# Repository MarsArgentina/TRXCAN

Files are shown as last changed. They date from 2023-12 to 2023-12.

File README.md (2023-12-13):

# TRXCAN
This project aims to develop an open platform that allows CANSAT developers to easily add RF communications and APRS tracking. It will also add GPIO and flight computer control a weather balloon.

This project is intended to fit inside an standardized CANSAT, measuring 66mm in diameter and 3CM in height. 

This project is currently in development. 

Currently the intended platform can be viewed in the following images:

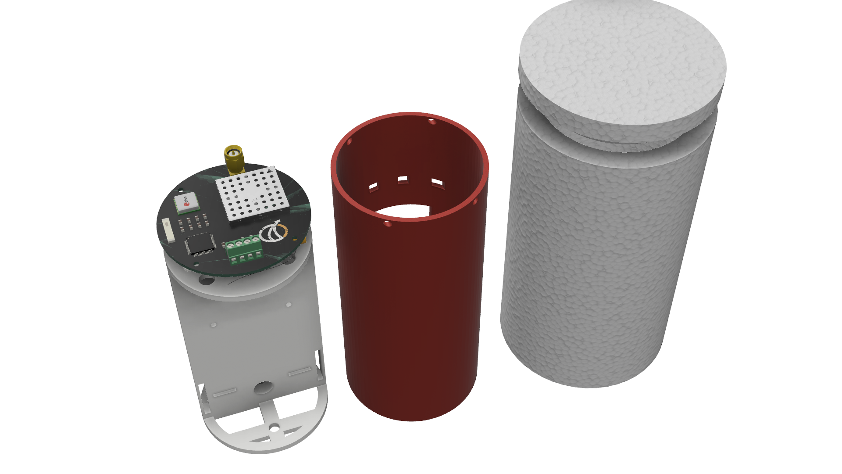
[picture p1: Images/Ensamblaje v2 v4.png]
Exploded view of assembly


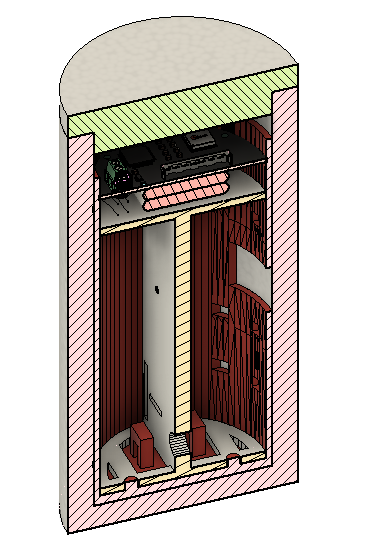
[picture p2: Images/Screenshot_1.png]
Section view of assembly


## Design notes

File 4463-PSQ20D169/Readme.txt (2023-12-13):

Content of WES0012.02.PSQ20D169.02.zip

\ASCII\
      \WES0012-02_ASCII.asc             	PADS Layout 9.4 layout file exported to PADS Layout V2005.0 ASCII format
                                        	 Can be imported with other CAD tools
      \WES0012-02-PSQ20D169-02_ASCII.txt	PADS Logic 9.4 schematic file exported to PADS Logic V2005.0 ASCII format
                                        	 Can be imported with other CAD tools
\CAD\
    \WES0012-02.pcb                     	PADS Layout 9.4 layout file
    \WES0012-02-PSQ20D169-02.sch        	PADS Logic 9.4 schematic file
\WES0012-02.pdf                         	Layout pdf file
\WES0012-02-PSQ20D169-02.pdf            	Schematic pdf file
\WES0012-02-PSQ20D169-02-BOM.xlsx       	Microsoft Excel file containing Bill of Materials, Component Coordinates and Manufacturing Notes
\WES0012-02-gerbers.zip                 	Compressed archive of gerber files for PCB manufacturing

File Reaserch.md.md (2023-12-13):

# Investigación

El desarrollo de RF utilizará el transceptor de RF SI4463 ó SI4464, ambos tienen la capacidad de transmitir y recibir en 144.930 MHz para usarlos como transmisores de APRS y receptores de comandos en formato **PACKET**. Esta elección se basa en el diseño de los módulos lightaprs que lo usan, por lo que ya tiene herencia de vuelo.

Cada micro tiene distintas topologías de diseño de los componentes pasivos que completan el circuito de transmisión y recepción. 

Las topologías se encuentran en el documento: ***AN629*** (ver carpeta adjunta).

En la nota de aplicación: ***AN648*** se explica en mayor detalle el diseño de TX.

Por otro lado, cada topología presentada tiene un diseño de referencia de PCB que se encuentra en la página:  [Technical Resource Search - Silicon Labs](https://www.silabs.com/support/resources.ct-schematic-and-layout-files.p-wireless_proprietary_ezradiopro-sub-ghz-wireless-ics_si4463.p-wireless_proprietary_ezradiopr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)

Por como funciona internamente el CHIP, la topología del circuito depende de la frecuencia central a transmitir y/o recibir. En caso de que las frecuencias de TX y RX sean muy distintas, se deberá usar un **switch** que selecione el circuito resonante correspondiente para TX o RX. O, en su defecto, usar antenas distintas.

Hay una relación inversamente proporcional en cuanto a la facilidad de cálculo del circuito y su selecctividad de componentes. Por ejemplo, hay circuitos de TRX que no requieren el switch pero las redes resonantes de TX y RX terminan acopladas entre si, lo que provoca que la disperción de componentes en una red afecte el rendimiento de la otra. 

Por otro lado, las redes separadas tienen más tolerancia de componentes pero requieren más elementos pasivos y hasta un elemento activo (el switch) que incrementan el costo y espacio requerido en la placa. 

## Selección de topología

En la nota de aplicación AN648 TABLA 1, se mencionan los distintos circuitos, y sus bandas de frecuencias aplicables. En el caso nuestro, elegimos el circuito de la fila 4: **SQW DT: 169M 20 dBm 70mA**  para ver el diseño y cálculos se referencian ambas notas de aplicación: ***AN648 y AN629***

Ya que nosotros queremos recibir y transmitir, con una sóla antena y reduciendo la cantidad de componentes, seleccionamos la topología de la ***AN629*** denominada: 

**Square-Wave Direct Tie Type Matching Network Layout Based on the
4463-PSQ20D169 (4463CPSQ20D169) Pico Board (Single Antenna without RF
Switch)**

Su diseño de referencia se encuentra descargado en el repo. Para abrirlo es necesario importarlo en Altium. También está convertido a un diseño maquetado en Kicad. 

# Problemática

Tenemos el problema de que luego de realizar un cálculo de BOM, sólo de comunicaciones, tenemos un costo de materiales de 25 USD. Si consideramos el resto de componentes y costo de manufactura el precio total de venta terminará rondando entre los 100 y 130 USD, muy similar a la solución propuesta por lightaprs. 

El plan de acción debería ser: 

1. Realizar un análisis de mercado para interpretar qué tanto estarían dispuestos a gastar los posibles interesados en nuestra propuesta vs qué tanto están dispuestos a gastar en un lanzamiento completo. Que incluya helio, globos o piniatas, etc. 

2. Ver si sería posible usar soluciones ya existentes de mercado como módulos transceptores:
   
   1. [RFM26W - HOPERF - Reliable original manufacturer of IoT key components](https://www.hoperf.com/modules/rf_transceiver/RFM26W.html)
   
   2. https://es.aliexpress.com/item/1005004147829291.html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
   
   3. CC1120 con disenio propio
   
   4. [LR62XE, the +30 dBm SX1262 LoRa Module &mdash; Fanstel](https://www.fanstel.com/lr62xe)

3. La solución por la que decantemos deberá ser TX y RX.

4. Ver si realmente los interesados quieren poder enviarle comandos al cansat.

> Antes de seguir con este desarrollo, deberíamos ponernos en contacto con colegios que hayan participado del concurso CANSAT para preguntar si les interesa la propuesta. 
> 
> Podríamos hacer un encuesta por mail que permita responder dudas mencionadas anteriormente.

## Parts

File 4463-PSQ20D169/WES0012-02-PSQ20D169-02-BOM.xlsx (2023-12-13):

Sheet: BOM
WES0012-02-PSQ20D169-02
Qty | Ref-Des | Value | Description | Type | Tolerance | Rated Voltage | Rated Current | Rated Power | TC Code | Package | RoHS | Manufacturer | Manufacturer Part Number | Distributor | Distributor Part Number
4 | C0, C3, C9, CC | 470pF | Ceramic Chip Capacitor |  | +/-10% | 50V |  |  | X7R | SMD 0402 | RoHS Compliant | Murata | GRM155R71H471K | DIGIKEY | 490-1300-2-ND
1 | C1 | 2.2uF | Ceramic Chip Capacitor |  | +/-10% | 10V |  |  | X5R | SMD 0603 | RoHS Compliant | Murata | GRM188R61A225K | DIGIKEY | 490-1545-2-ND
2 | C2, C11 | 100nF | Ceramic Chip Capacitor |  | +/-10% | 16V |  |  | X7R | SMD 0402 | RoHS Compliant | Murata | GRM155R71C104K | DIGIKEY | 490-3261-2-ND
1 | C4 | 100pF | Ceramic Chip Capacitor |  | +/-5% | 50V |  |  | C0G | SMD 0402 | RoHS Compliant | Murata | GRM1555C1H101J | DIGIKEY | 490-3458-2-ND
1 | C6 | N.F. | Ceramic Chip Capacitor |  |  |  |  |  |  | SMD 0402 | RoHS Compliant | Murata | GRM15 series | DIGIKEY
1 | C7 | 3.0pF | Ceramic Chip Capacitor |  | +/-0.25pF | 50V |  |  | C0G | SMD 0402 | RoHS Compliant | Murata | GRM1555C1H3R0C | DIGIKEY | 490-3205-2-ND
1 | C8 | 2.0pF | Ceramic Chip Capacitor |  | +/-0.25pF | 50V |  |  | C0G | SMD 0402 | RoHS Compliant | Murata | GRM1555C1H2R0C | DIGIKEY | 490-3204-2-ND
2 | CH, CM3 | 11pF | Ceramic Chip Capacitor |  | +/-5% | 50V |  |  | C0G | SMD 0402 | RoHS Compliant | Murata | GRM1555C1H110J | DIGIKEY | 490-3216-2-ND
2 | CM1, CM2 | 18pF | Ceramic Chip Capacitor |  | +/-5% | 50V |  |  | C0G | SMD 0402 | RoHS Compliant | Murata | GRM1555C1H180J | DIGIKEY | 490-1281-2-ND
1 | CR1 | 12pF | Ceramic Chip Capacitor |  | +/-5% | 50V |  |  | C0G | SMD 0402 | RoHS Compliant | Murata | GRM1555C1H120J | DIGIKEY | 490-1279-2-ND
1 | CR2 | 6.2pF | Ceramic Chip Capacitor |  | +/-0.5pF | 50V |  |  | C0G | SMD 0402 | RoHS Compliant | Murata | GRM1885C1H6R2D | DIGIKEY | 490-1394-2-ND
1 | J1 | N.F.
1 | LC | 330nH | Wirewound Ceramic Chip Inductor |  | +/-5% |  |  |  |  | SMD 0603 |  | CoilCraft | 0603CS family
3 | LF2, LF3, LF4 | 150nH | Multilayer Chip Inductor |  | +/-5% |  | 140mA |  |  | SMD 0402 | RoHS Compliant | Murata | LQG15HSR15 | DIGIKEY | 490-2637-2-ND
1 | LH | 82nH | Wirewound Ceramic Chip Inductor |  | +/-5% |  | 315mA |  |  | SMD 0402 | RoHS Compliant | CoilCraft | 0402HP-82NXJL
2 | LM1, LM3 | 47nH | Wirewound Ceramic Chip Inductor |  | +/-5% |  | 420mA |  |  | SMD 0402 | RoHS Compliant | CoilCraft | 0402HP-47NXJL
1 | LM2 | 68nH | Wirewound Ceramic Chip Inductor |  | +/-5% |  | 320mA |  |  | SMD 0402 | RoHS Compliant | CoilCraft | 0402HP-68NXJL
1 | LM4 | 27nH | Wirewound Ceramic Chip Inductor |  | +/-5% |  | 450mA |  |  | SMD 0402 | RoHS Compliant | CoilCraft | 0402HP-27NXJL
1 | LR1 | 220nH | Wirewound Ceramic Chip Inductor |  | +/-5% |  | 160mA |  |  | SMD 0402 | RoHS Compliant | CoilCraft | 0402HPH-R22XJL
1 | LR2 | 150nH | Wirewound Ceramic Chip Inductor |  | +/-5% |  | 240mA |  |  | SMD 0402 | RoHS Compliant | CoilCraft | 0402HPH-R15XJL
1 | Q1 | 30MHz | Crystal |  | 10ppm |  |  |  |  | Ceramic SMD; 2.5X2X0.6mm | RoHS | Tai-Saw Technology | TZ1430A
1 | RH | 50R | Chip Resistor | Thick Film | +/-1% |  |  | 1/16W |  | SMD 0402 | RoHS Compliant | Yageo | RC0402FR-0749R9L | DIGIKEY | 311-49.9LRTR-ND
1 | TRX | A97594-ND | SMA Vertical Female Connector | 5-1814832-1 |  |  |  |  |  | Through Hole | RoHS Compliant | TE Connectivity | 5-1814832-1 | Digikey | A97594-ND
1 | U1 | Si4463 | ISM TRANSCEIVER +20dBm | Si4463 |  | 1.8V - 3.6V |  |  |  | QFN-20 4x4mm | RoHS | Silicon Labs | Si4463
1 | U4 | BMI-S-203-F + BMI-S-203-C | SHIELD + Cap | SHIELD + Cap |  | - | - | - | - | SMD 26.1x26.1mm | RoHS Compliant | Laird Technologies EMI | BMI-S-203-F + BMI-S-203-C | Digi-Key | 903-1052-1-ND + 903-1015-ND
 | GRM155R71H471K | 4
 | GRM188R61A225K | 1
 | GRM155R71C104K | 2
 | GRM1555C1H101J | 1
 | GRM15 series | 1
 | GRM1555C1H3R0C | 1
 | GRM1555C1H2R0C | 1
 | GRM1555C1H110J | 2
 | GRM1555C1H180J | 2
 | GRM1555C1H120J | 1
 | GRM1885C1H6R2D | 1
 | 0603CS family | 1
 | LQG15HSR15 | 3
 | 0402HP-82NXJL | 1
 | 0402HP-47NXJL | 2
 | 0402HP-68NXJL | 1
 | 0402HP-27NXJL | 1
 | 0402HPH-R22XJL | 1
 | 0402HPH-R15XJL | 1
 | TZ1430A | 1
 | RC0402FR-0749R9L | 1
 | 5-1814832-1 | 1
 | Si4463 | 1
 | BMI-S-203-F + BMI-S-203-C | 1

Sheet: COORD
WES0012-02-PSQ20D169-02
Item | Ref-Des | Value | Description | Package | Layer | X [mm] | Y [mm] | Orient.
1 | C0 | 470pF | Ceramic Chip Capacitor | SMD 0402 | Top | 20.32 | 16.18 | 270
2 | C1 | 2.2uF | Ceramic Chip Capacitor | SMD 0603 | Top | 14.64 | 12.14 | 90
3 | C2 | 100nF | Ceramic Chip Capacitor | SMD 0402 | Top | 16.06 | 13.87 | 270
4 | C3 | 470pF | Ceramic Chip Capacitor | SMD 0402 | Top | 18.01 | 13.87 | 270
5 | C4 | 100pF | Ceramic Chip Capacitor | SMD 0402 | Top | 17.02 | 13.87 | 270
6 | C6 | N.F. | Ceramic Chip Capacitor | SMD 0402 | Top | 21.28 | 19.94 | 270
7 | C7 | 3.0pF | Ceramic Chip Capacitor | SMD 0402 | Top | 21.28 | 22.78 | 270
8 | C8 | 2.0pF | Ceramic Chip Capacitor | SMD 0402 | Top | 21.28 | 25.58 | 270
9 | C9 | 470pF | Ceramic Chip Capacitor | SMD 0402 | Top | 16.87 | 16.21 | 270
10 | C11 | 100nF | Ceramic Chip Capacitor | SMD 0402 | Bottom | 4.14 | 29.45 | 270
11 | CC | 470pF | Ceramic Chip Capacitor | SMD 0402 | Top | 20.32 | 30.2 | 90
12 | CH | 11pF | Ceramic Chip Capacitor | SMD 0402 | Top | 19.86 | 17.58 | 0
13 | CM1 | 18pF | Ceramic Chip Capacitor | SMD 0402 | Top | 19.86 | 21.36 | 0
14 | CM2 | 18pF | Ceramic Chip Capacitor | SMD 0402 | Top | 19.86 | 24.18 | 0
15 | CM3 | 11pF | Ceramic Chip Capacitor | SMD 0402 | Top | 19.86 | 26.97 | 0
16 | CR1 | 12pF | Ceramic Chip Capacitor | SMD 0402 | Top | 23.61 | 16.66 | 180
17 | CR2 | 6.2pF | Ceramic Chip Capacitor | SMD 0402 | Top | 21.25 | 17.12 | 270
18 | J1 | N.F. |  |  | Top | 38.23 | 1.69 | 180
19 | LC | 330nH | Wirewound Ceramic Chip Inductor | SMD 0603 | Top | 18.64 | 16 | 180
20 | LF2 | 150nH | Multilayer Chip Inductor | SMD 0402 | Top | 25.78 | 13.44 | 0
21 | LF3 | 150nH | Multilayer Chip Inductor | SMD 0402 | Top | 26.37 | 14.4 | 0
22 | LF4 | 150nH | Multilayer Chip Inductor | SMD 0402 | Top | 24.54 | 14.58 | 0
23 | LH | 82nH | Wirewound Ceramic Chip Inductor | SMD 0402 | Top | 19.86 | 18.54 | 0
24 | LM1 | 47nH | Wirewound Ceramic Chip Inductor | SMD 0402 | Top | 20.32 | 19.94 | 270
25 | LM2 | 68nH | Wirewound Ceramic Chip Inductor | SMD 0402 | Top | 20.32 | 22.78 | 270
26 | LM3 | 47nH | Wirewound Ceramic Chip Inductor | SMD 0402 | Top | 20.32 | 25.58 | 270
27 | LM4 | 27nH | Wirewound Ceramic Chip Inductor | SMD 0402 | Top | 20.32 | 28.37 | 270
28 | LR1 | 220nH | Wirewound Ceramic Chip Inductor | SMD 0402 | Top | 21.71 | 15.72 | 0
29 | LR2 | 150nH | Wirewound Ceramic Chip Inductor | SMD 0402 | Top | 22.17 | 17.12 | 270
30 | Q1 | 30MHz | Crystal | Ceramic SMD; 2.5X2X0.6mm | Top | 25.34 | 10.97 | 270
31 | RFP1 | SFH31-NPPB-D10-SP-BK | Connector, Female Socket, 2x10 pos, 1,27mm SMD | SMD | Bottom | 36.46 | 12.57 | 270
32 | RFP2 | SFH31-NPPB-D10-SP-BK | Connector, Female Socket, 2x10 pos, 1,27mm SMD | SMD | Bottom | 4.59 | 12.57 | 270
33 | RH | 50R | Chip Resistor | SMD 0402 | Top | 18.06 | 18.52 | 0
34 | S1 | 13x25mm | Part and testing information about the specific PCB |  | Bottom | 33.02 | 14.22 | 0
35 | SJ1 |  | 1X2 Pin Solderable Jumper |  | Top | 14.24 | 14.55 | 270
36 | TRX | A97594-ND | SMA Vertical Female Connector | Through Hole | Top | 17.53 | 39.78 | 0
37 | TXRAMP |  | Testpoint |  | Top | 17.57 | 12.53 | 0
38 | U1 | Si4463 | ISM TRANSCEIVER +20dBm | QFN-20 4x4mm | Top | 21.13 | 12.31 | 270
39 | U3 | 24AA64T-I/MNY | 64k I2C Serial EEPROM | DFN-8 2x3mm | Bottom | 3.52 | 26.48 | 90
40 | U4 | BMI-S-203-F + BMI-S-203-C | SHIELD + Cap | SMD 26.1x26.1mm | Top | 6.85 | 5.98 | 0

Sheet: Manuf. Notes
WES0012-02-PSQ20D169-02
 | PCB Material: | FR-4
 | PCB Stackup:
 | TOP | 18um | Copper
 | Prepreg | 400um | FR-4
 | IN2 | 35um | Coppper
 | Core | 710um | FR-4
 | IN3 | 35um | Coppper
 | Prepreg | 400um | FR-4
 | BOT | 18um | Copper
 | Given hole sizes are: | Finished hole sizes
 | Solder Stop Mask CS: | Yes | Blue
 | Solder Stop Mask SS: | Yes | Blue
 | Silkscreen CS: | Yes | White
 | Silkscreen SS: | Yes | White
 | Leadfree Coating: | Chemical Aureus

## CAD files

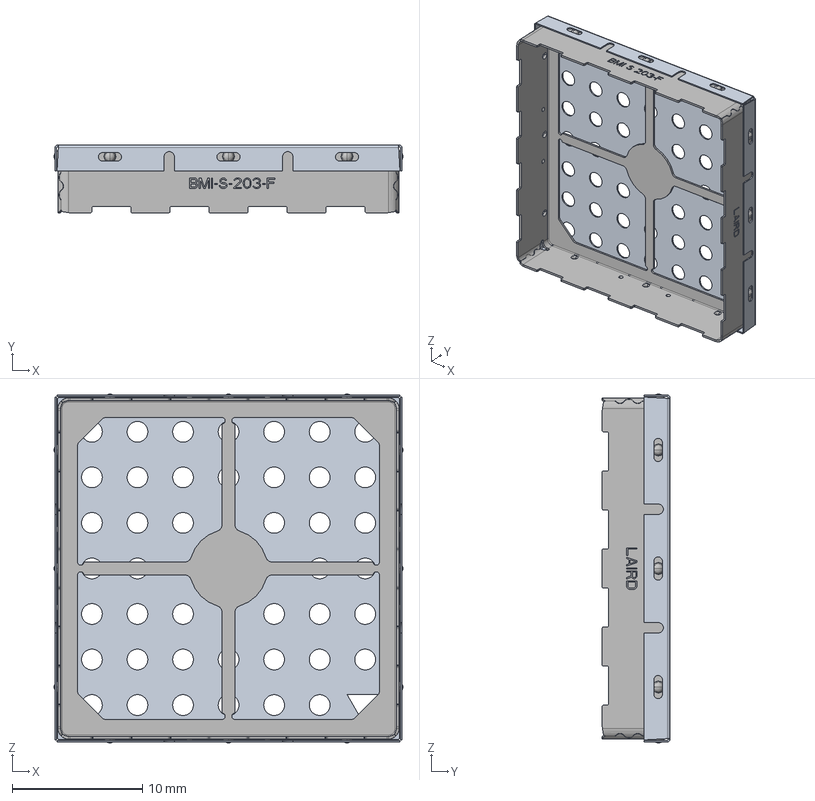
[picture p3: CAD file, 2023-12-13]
MAQUETA CAD/bmi-s-203-assembly-stp-file.STP
26.8 x 5.21 x 26.8 mm
BMI-S-203-F
BMIS-203-C

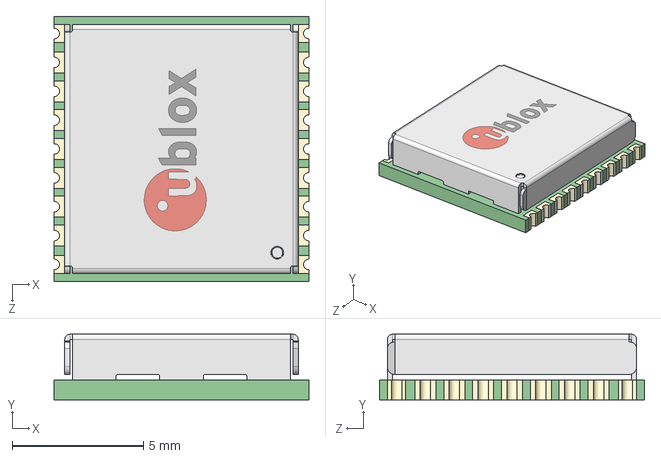
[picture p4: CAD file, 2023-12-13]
MAQUETA CAD/User Library-MAX-M8 u-blox M8 Concurrent GNSS Module.step
9.70 x 2.50 x 10.1 mm

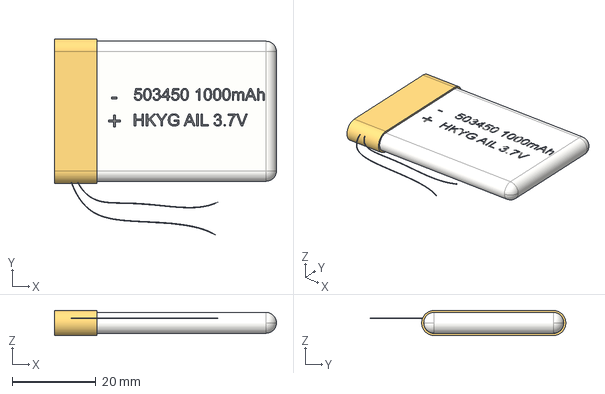
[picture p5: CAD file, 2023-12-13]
MAQUETA CAD/Bateria LiPo 3.7V 1000mA 503450 v23.step
53.1 x 46.8 x 6.00 mm

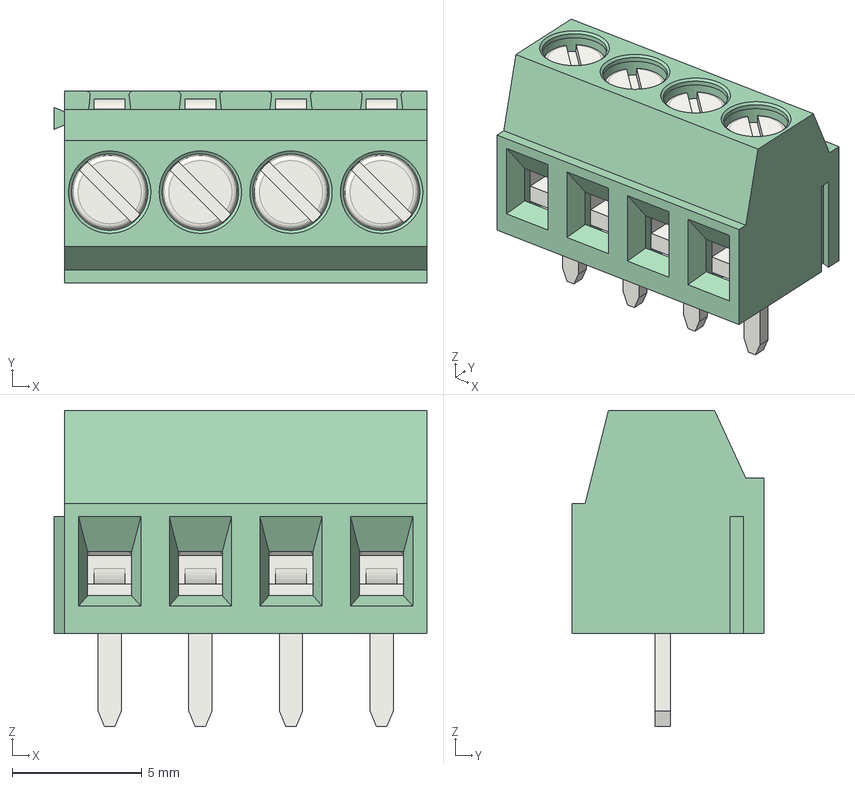
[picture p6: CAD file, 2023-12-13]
MAQUETA CAD/PCB Terminal Block 4 DEG381-3.5.step
14.4 x 7.40 x 12.2 mm
Plastic Housing003
Pin 004
Clamp Block003
M1.6x3-Screw017

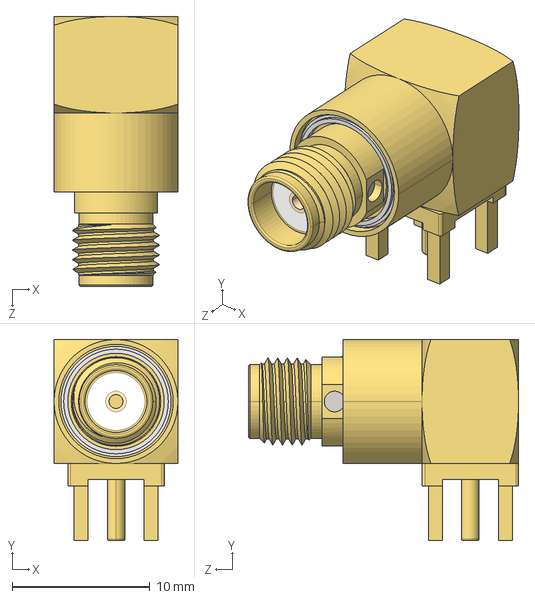
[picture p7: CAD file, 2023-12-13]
MAQUETA CAD/BM61276.STEP
9.00 x 14.6 x 19.6 mm

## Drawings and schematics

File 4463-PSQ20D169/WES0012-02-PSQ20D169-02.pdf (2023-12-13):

## RF Section

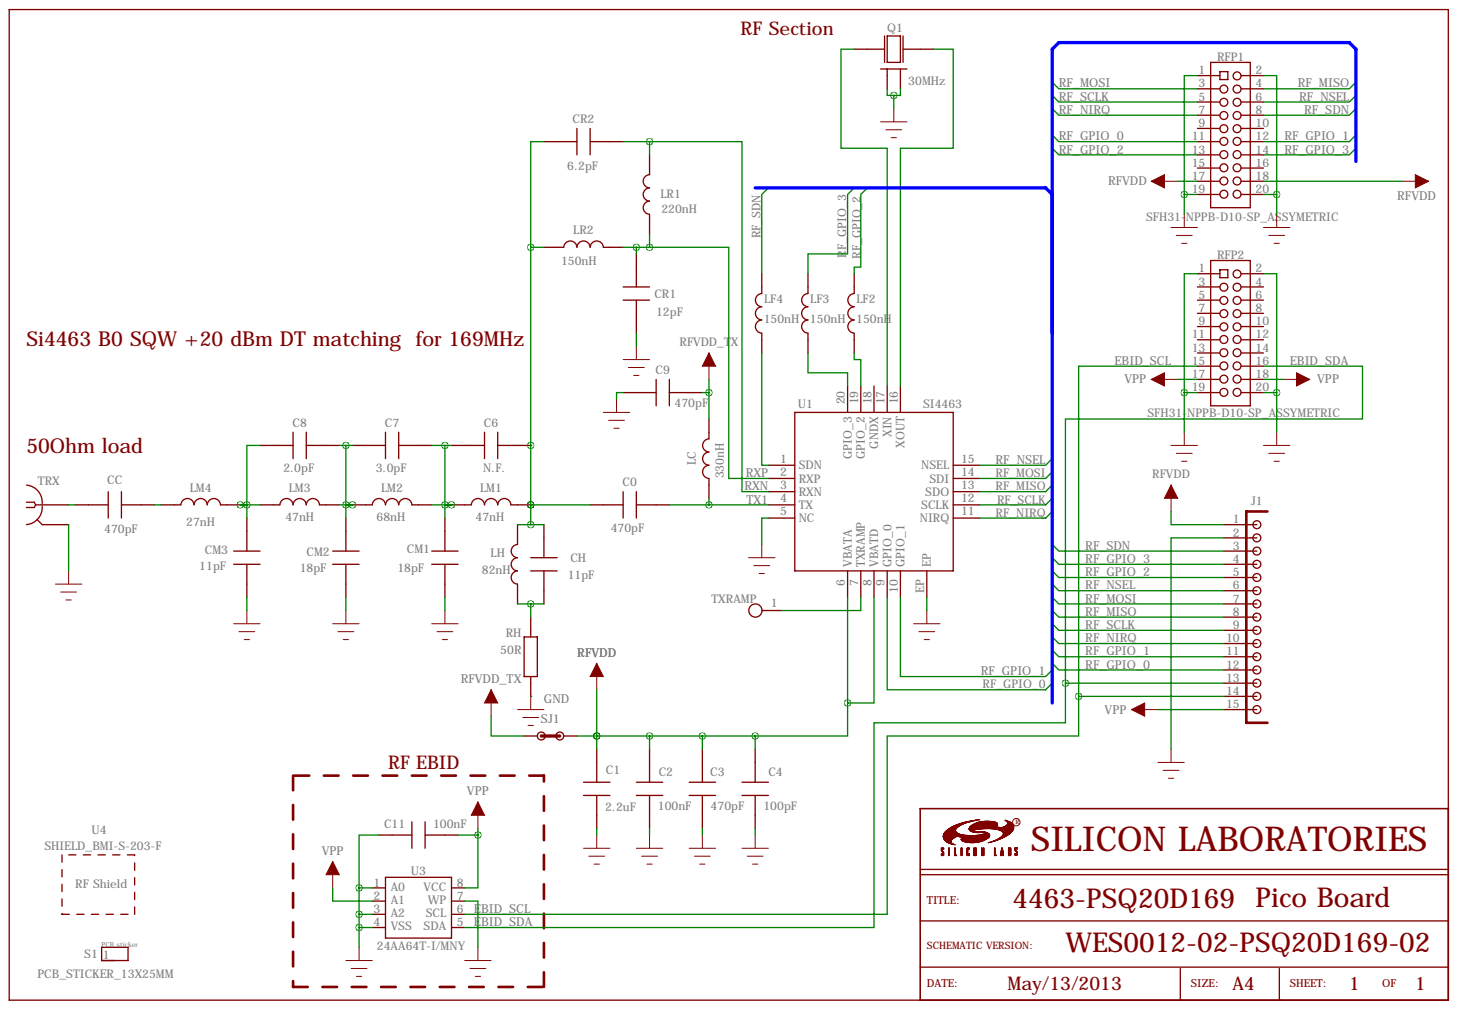
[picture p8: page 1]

Si4463 B0 SQW +20 dBm DT matching for 169MHz

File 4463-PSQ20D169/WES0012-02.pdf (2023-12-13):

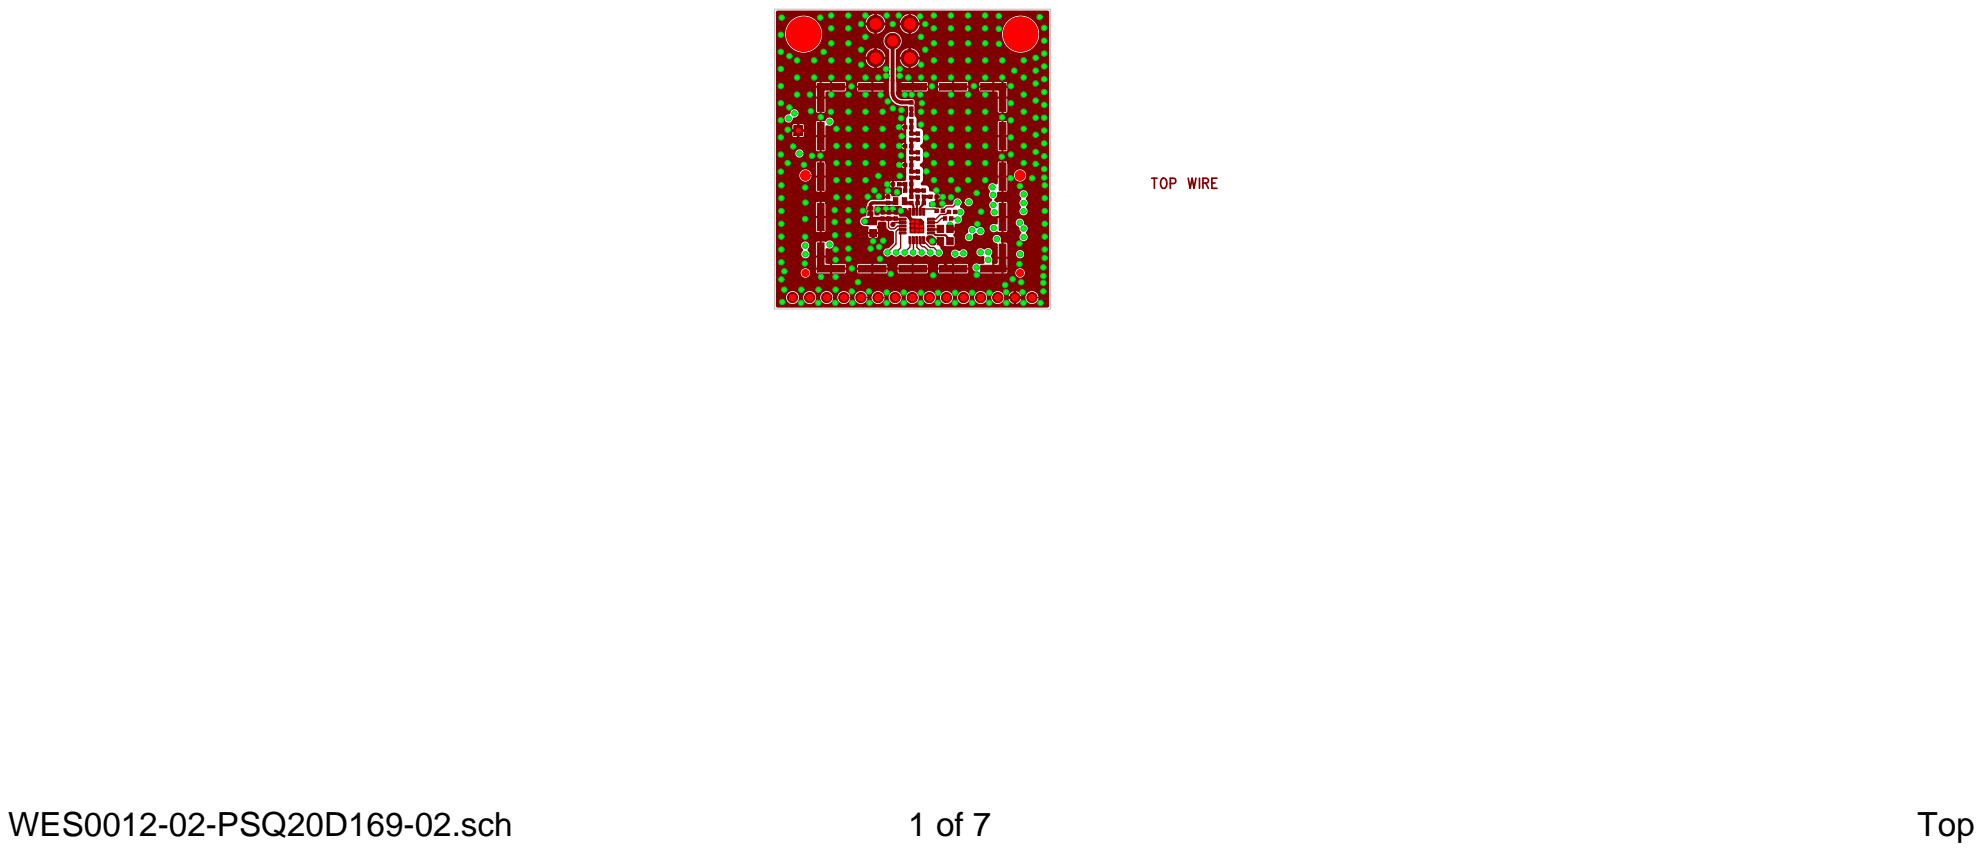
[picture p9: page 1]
WES0012-02-PSQ20D169-02.sch; Top; TOP WIRE; C2C²x1 C²x2 C4C⁴x1 C⁴x2; Q1Q¹x1 Q¹x2 Q¹x3 Q¹x4; C0C⁰x1 C⁰x2; CM2 CM²x1; CM²x2; C1C¹x1 C¹x2; C3C³x1 C³x2; C9C⁹x1 C⁹x2; U3U³x9; LM1LM¹x1 LM¹x2 LM2LM²x1 LM²x2; CM1 CM¹x1; CM¹x2 LM3LM³x1 LM³x2 C6C⁶x1 C⁶x2; CM3 CM³x1; CM³x2 CR2 CR1 CR¹x2; CR¹x1 CR²x1 CR²x2; LR1LR¹x1; LR¹x2 LR2LR²x1 LR²x2 U4TXRAMPTXRAMPx1 U⁴xGND⁰; U⁴xGND¹; U⁴xGND²; U⁴xGND³; U⁴xGND⁴ U⁴xGND⁵ U⁴xGND⁶ U⁴xGND⁷ U⁴xGND⁸ U⁴xGND⁹U⁴xGND¹⁴; U⁴xGND¹³; U⁴xGND¹²; U⁴xGND¹¹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

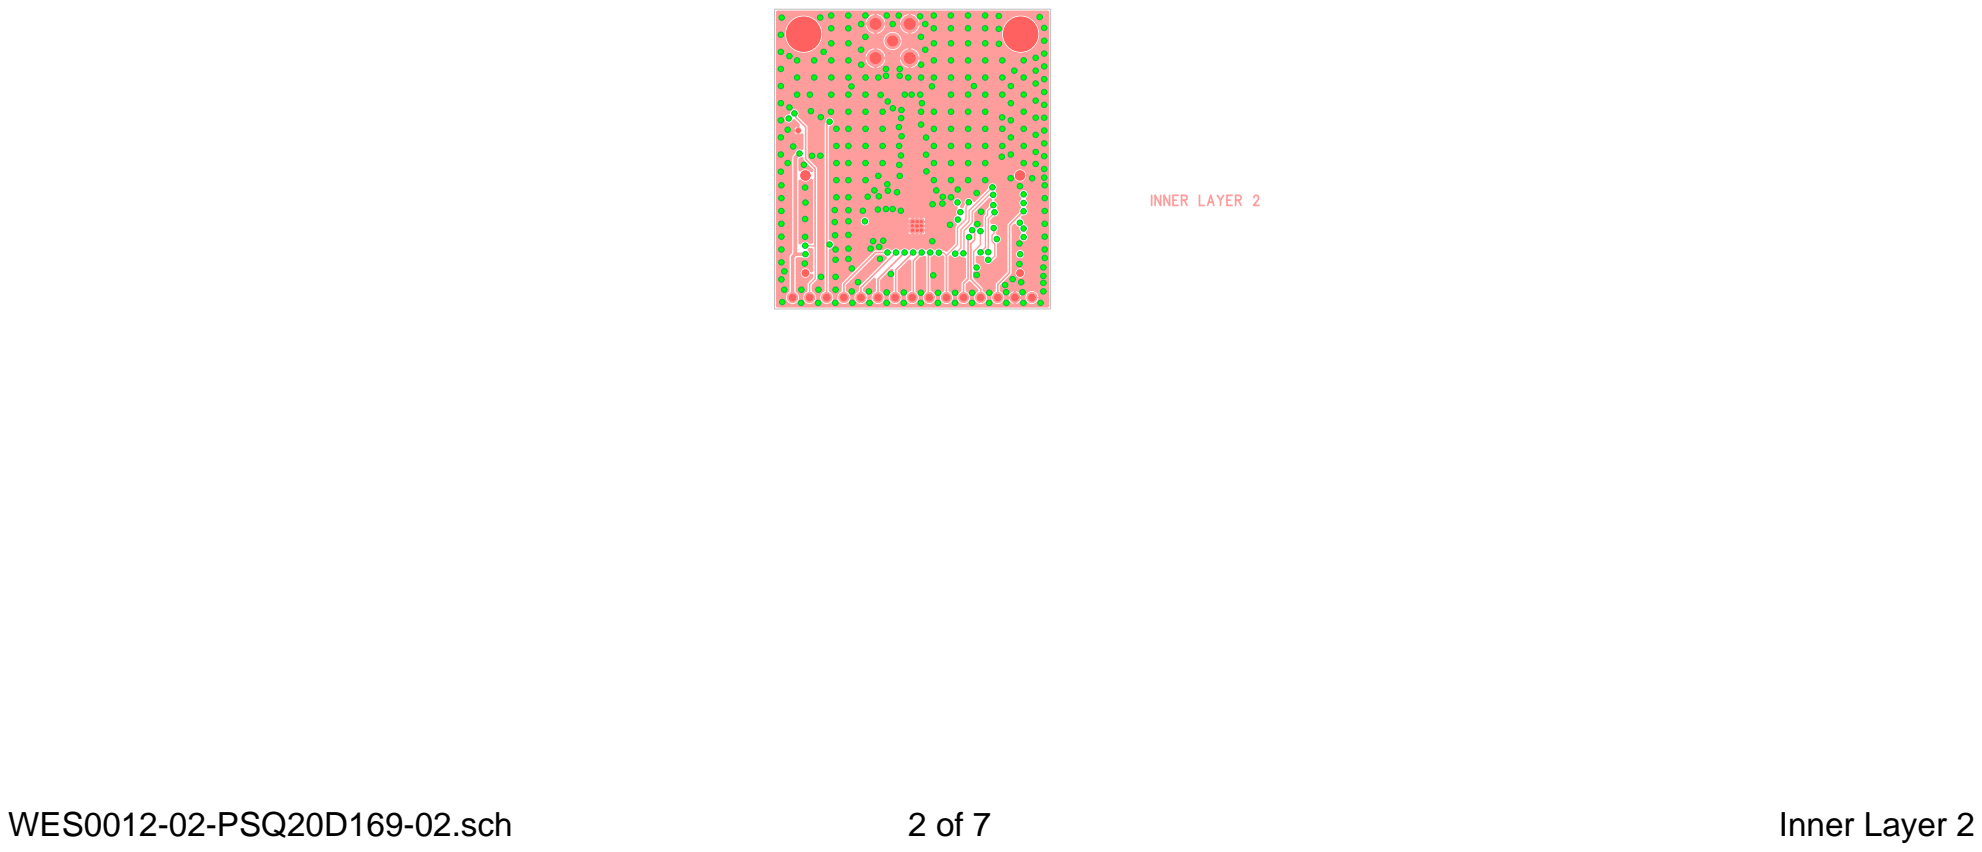
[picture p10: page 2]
WES0012-02-PSQ20D169-02.sch; Inner Layer 2; INNER LAYER 2; U3U³x9; TRXTRXx1TRXx2; TRXx3 TRXx5; TRXx4; X1X¹x1; X2X²x1; RFP1RFP¹x21; RFP2; RFP1x22; RFP2x21 RFP2x22

U1U¹xEPU¹xEP² U¹xEP³ U¹xEP⁴ U¹xEP⁵ U¹xEP⁶ U¹xEP⁷ U¹xEP⁸ U¹xEP⁹

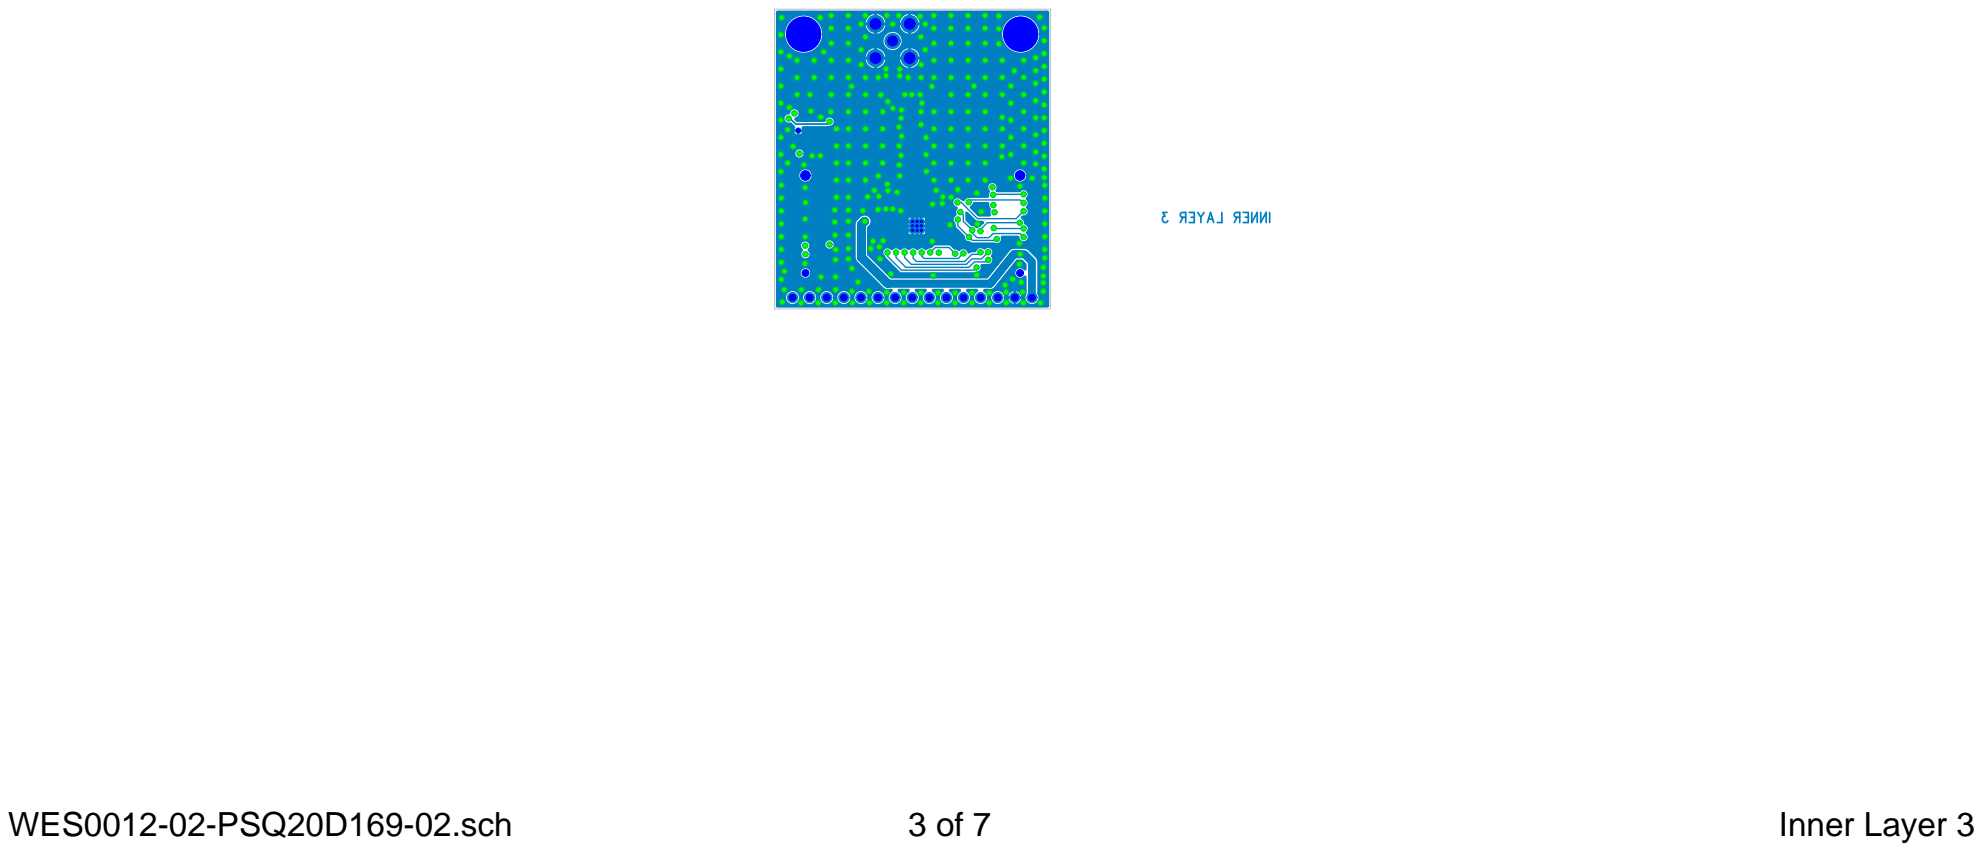
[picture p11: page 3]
WES0012-02-PSQ20D169-02.sch; Inner Layer 3; U3U³x9; TRXTRXx1TRXx2; TRXx3 TRXx5; TRXx4; X1X¹x1; X2X²x1; RFP1RFP¹x21; RFP2; RFP1x22; RFP2x21 RFP2x22

U1U¹xEPU¹xEP² U¹xEP³ U¹xEP⁴ U¹xEP⁵ U¹xEP⁶ U¹xEP⁷ U¹xEP⁸ U¹xEP⁹

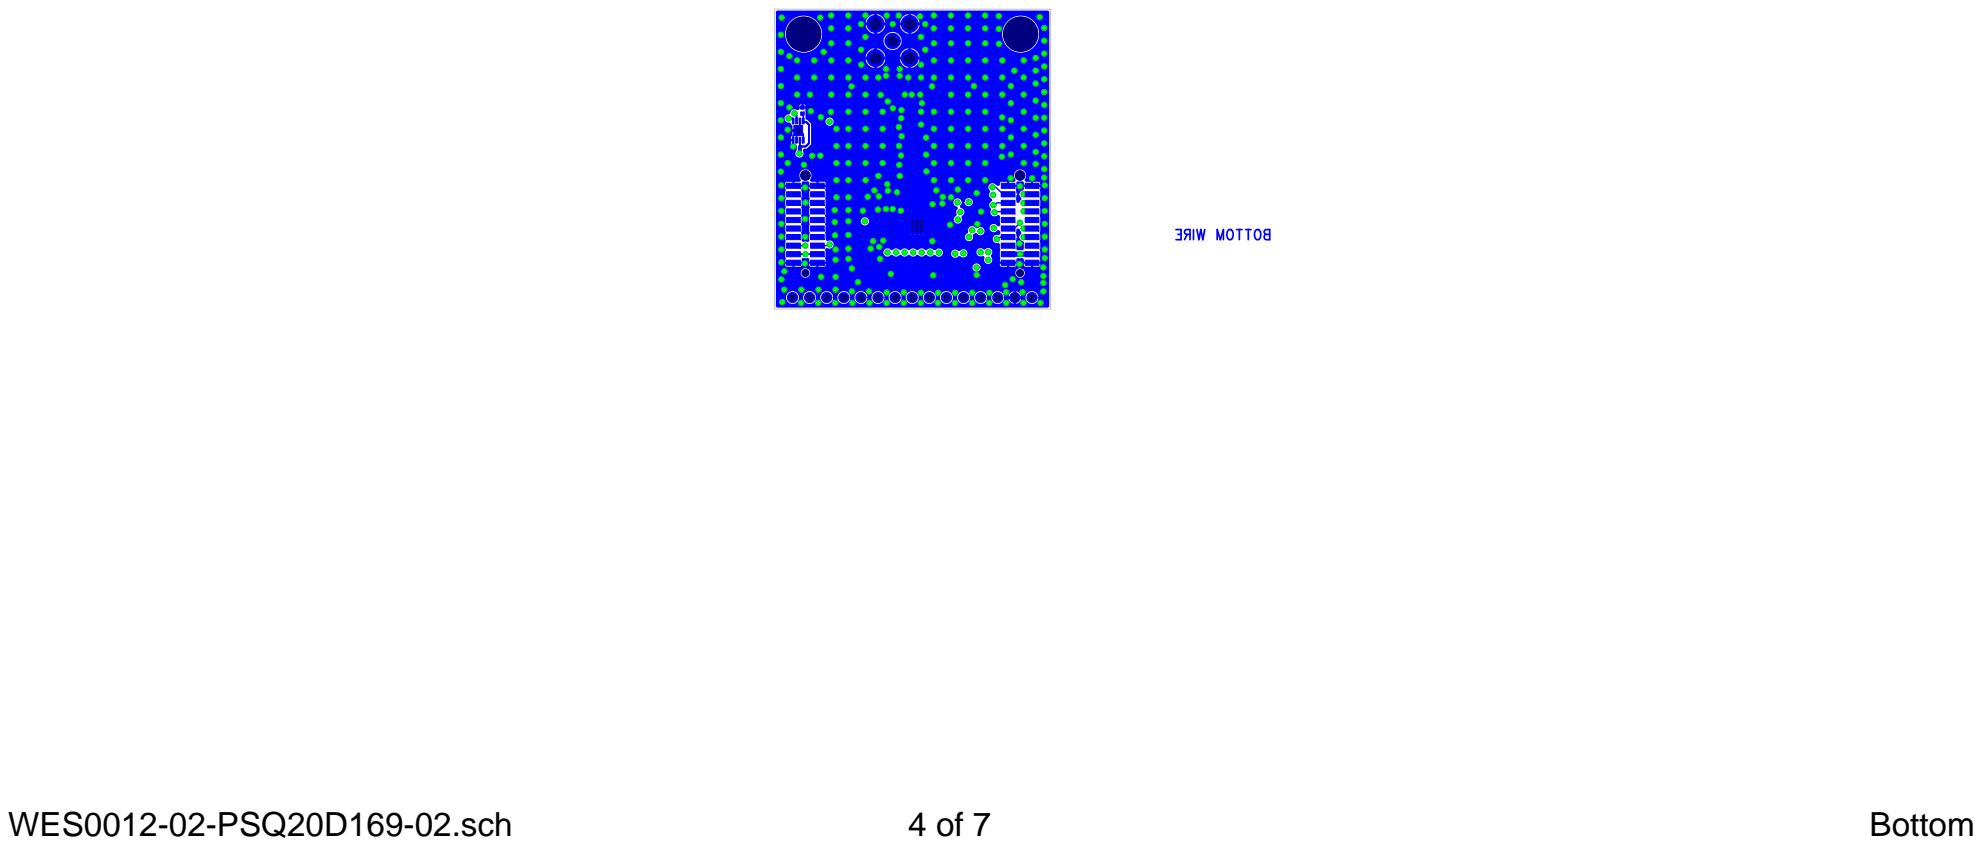
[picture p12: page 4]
WES0012-02-PSQ20D169-02.sch; Bottom; C11C¹¹x1 C¹¹x2 U3U³x4 U³x3 U³x2 U³x1 U³x5 U³x6 U³x7 U³x8 U³x9; TRXTRXx1TRXx2; TRXx3 TRXx5; TRXx4; X1X¹x1; X2X²x1; RFP1 RFP¹x1; RFP¹x2 RFP¹x3; RFP¹x4 RFP¹x5; RFP¹x6 RFP¹x7; RFP¹x8 RFP¹x9; RFP¹x10 RFP¹x11; RFP¹x12 RFP¹x13; RFP¹x14 RFP¹x15; RFP¹x16 RFP¹x17; RFP¹x18 RFP¹x19; RFP¹x20 RFP¹x21; RFP2; RFP1x22; RFP2x1; RFP2x2; RFP2x3; RFP2x4; RFP2x5; RFP2x6; RFP2x7; RFP2x8; RFP2x9; RFP2x10; RFP2x11; RFP2x12; RFP2x13; RFP2x14; RFP2x15; RFP2x16; RFP2x17; RFP2x18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

U1U¹xEPU¹xEP² U¹xEP³ U¹xEP⁴ U¹xEP⁵ U¹xEP⁶ U¹xEP⁷ U¹xEP⁸ U¹xEP⁹

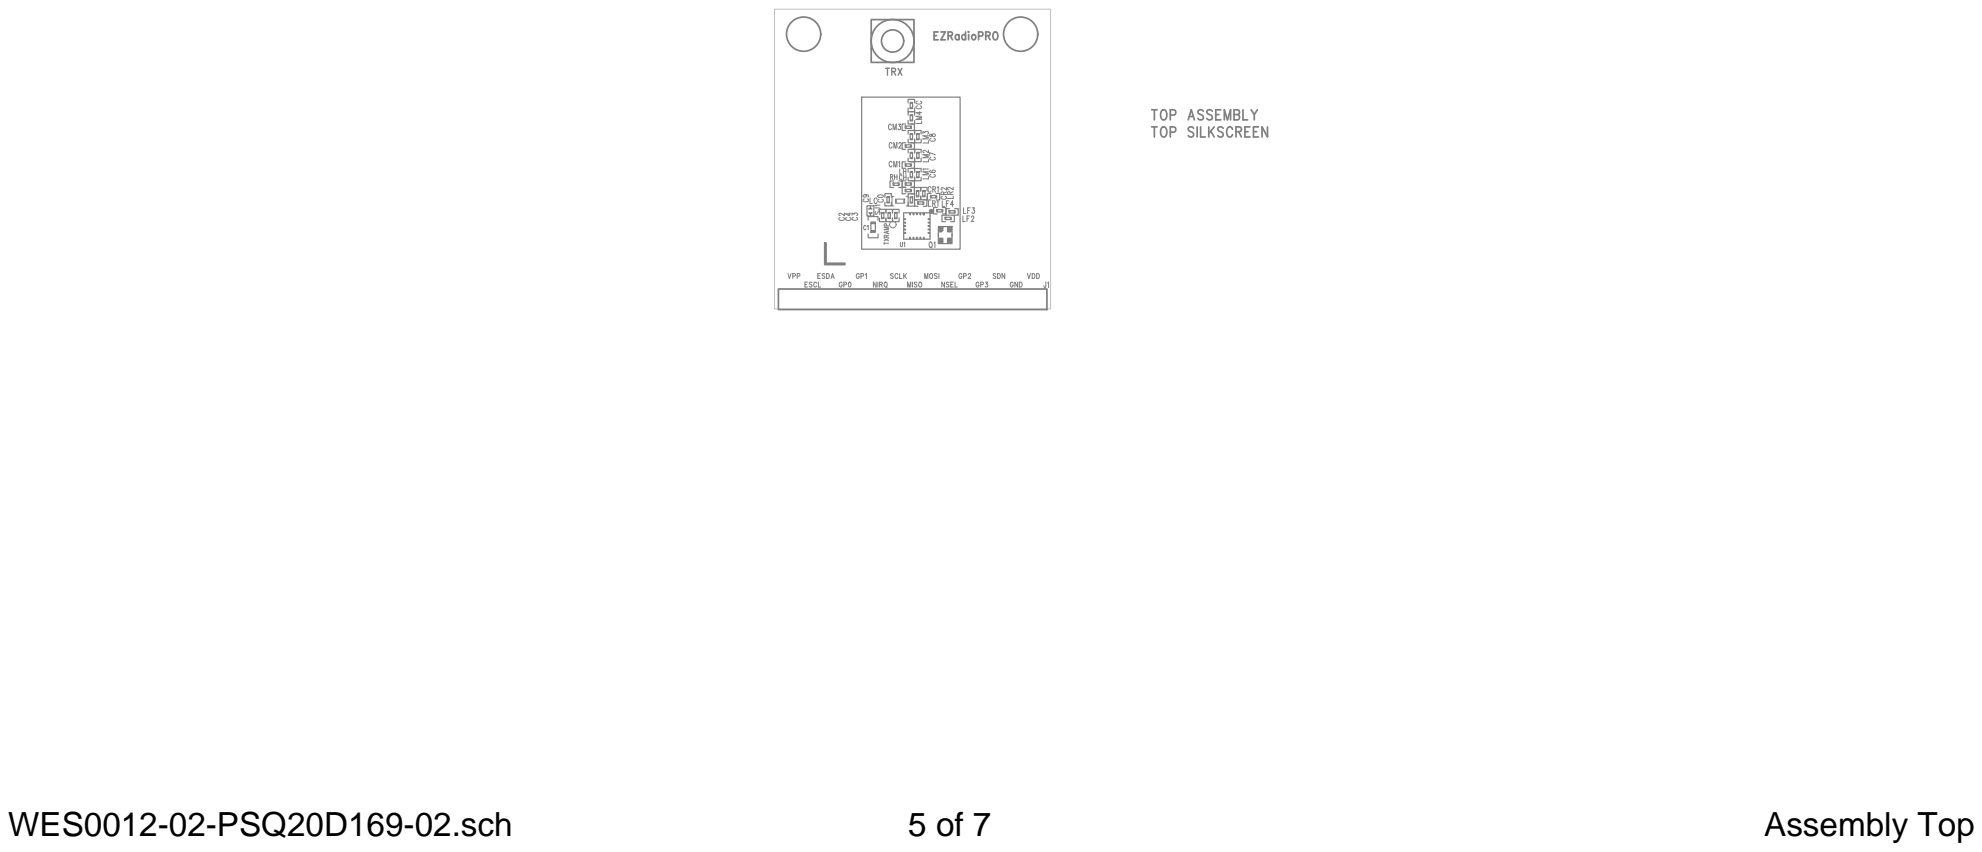
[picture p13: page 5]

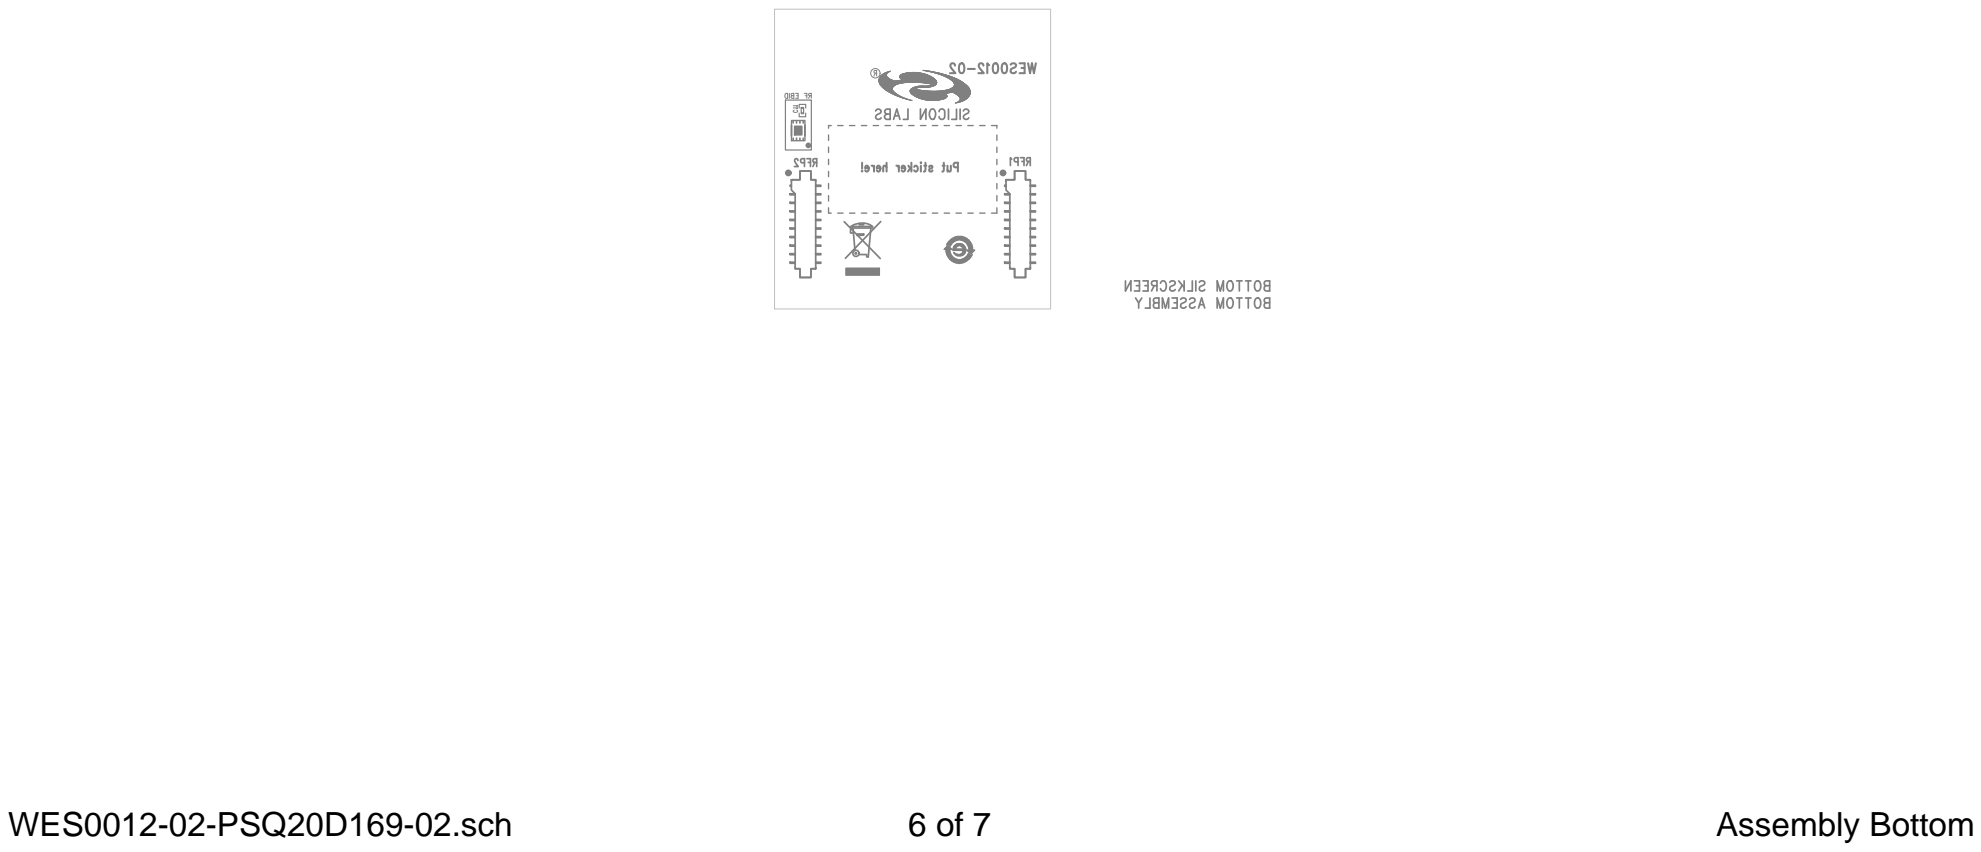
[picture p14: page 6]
WES0012-02-PSQ20D169-02.sch; Assembly Bottom; RFP2; RFP1 S1 U³x9; TRXTRXx1TRXx2; TRXx3 TRXx5; TRXx4; X1X¹x1; X2X²x1; RFP1x22; RFP2x21 RFP2x22

Put sticker here!
RFP1RFP¹x21

U1U¹xEPU¹xEP² U¹xEP³ U¹xEP⁴ U¹xEP⁵ U¹xEP⁶ U¹xEP⁷ U¹xEP⁸ U¹xEP⁹

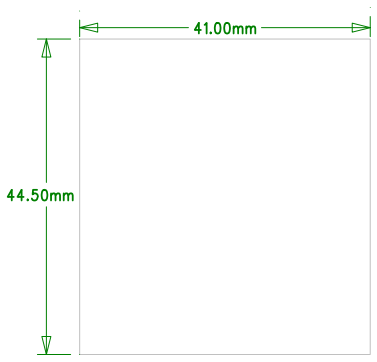
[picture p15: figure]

WES0012-02-PSQ20D169-02.sch | 7 of 7 | Manufacturing Notes

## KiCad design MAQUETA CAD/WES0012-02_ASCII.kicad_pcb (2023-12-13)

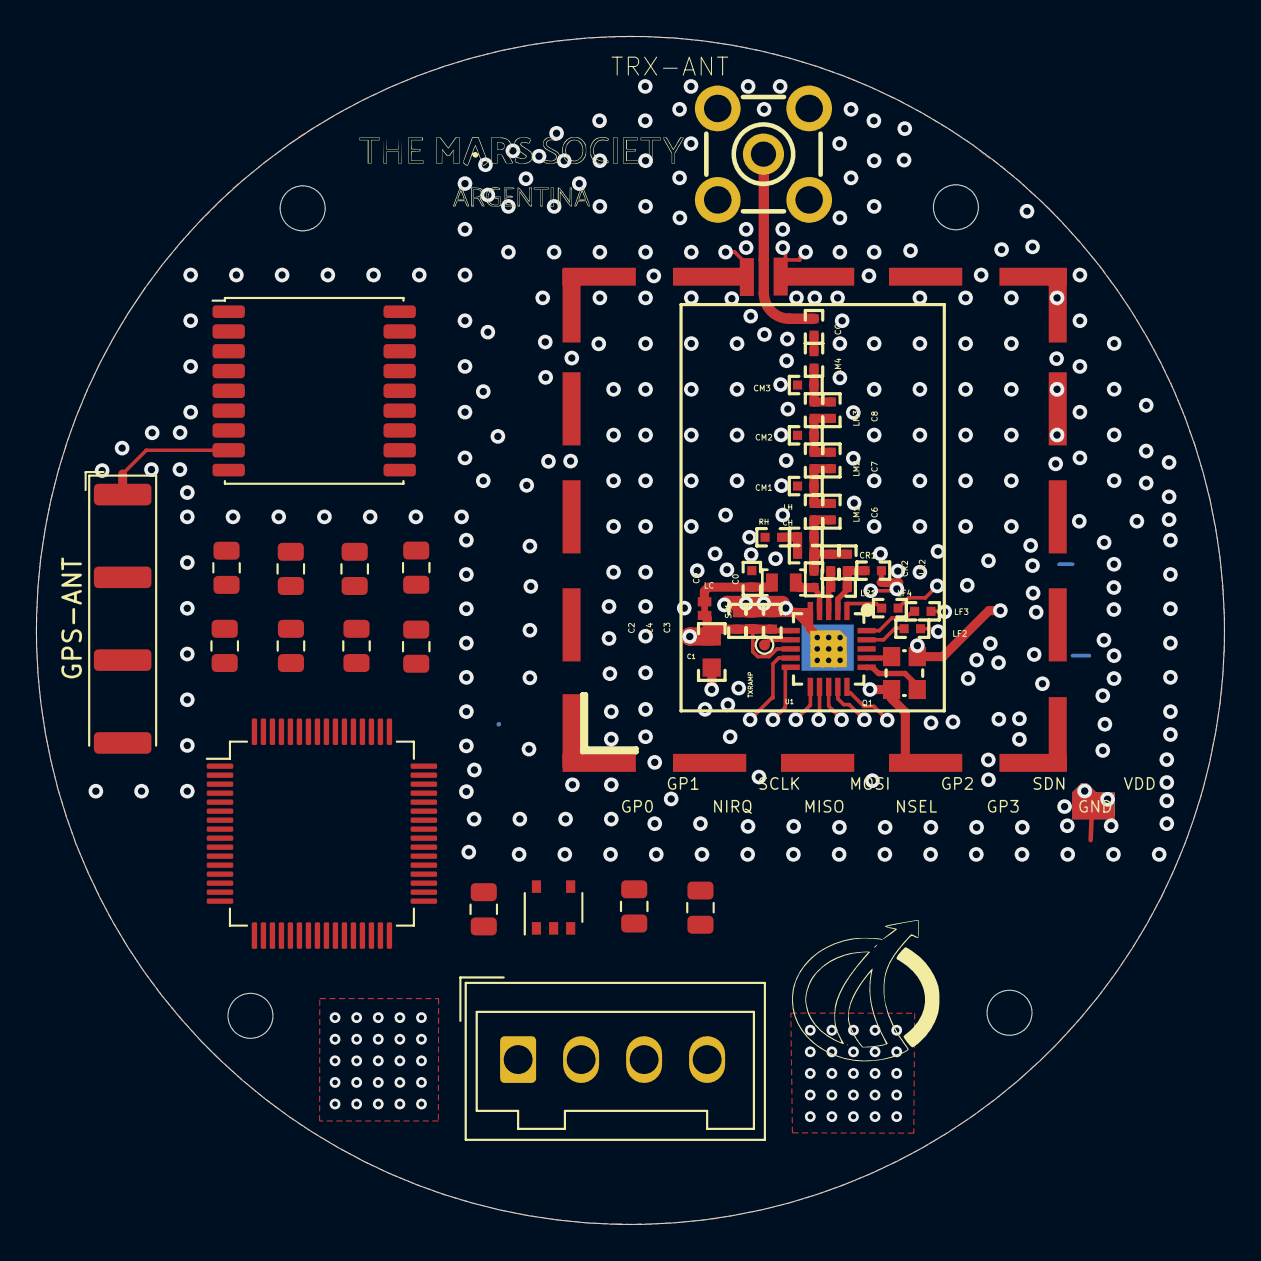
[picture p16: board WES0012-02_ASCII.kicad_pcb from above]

Board: 4 copper layers, 66.0 x 66.0 mm, 35 parts (0 on the bottom side), 19 nets.

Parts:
C0, C2, C3, C4, C6, C7, C8, C9: SMD0402
C1: SMD0603
CC: SMD0402
CH: SMD0402
CM1, CM2, CM3: SMD0402
CR1, CR2: SMD0402
GPS-ANT: Antenova_SR4G013_GPS
LC: IND0603
LF2, LF3, LF4: SMD0402
LH: SMD0402
LM1, LM2, LM3, LM4: SMD0402
LR1, LR2: SMD0402
Q1: CRYSTAL_4PIN_SMD_2.5X2MM
RH: SMD0402
SJ1: JP_SMD_2P_20X30_SHORT
TRX-ANT: SMA-V
TXRAMP: TESTPOINT_24
U1: QFN-20
U4: SHIELD_BMI-S-203-F

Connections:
$$$6546: TXRAMP.1, U1.7
$$$7296: CC.2, TRX-ANT.1
$$$10983: CH.1, LH.1, RH.2
$$$11456: Q1.3, U1.16
$$$11466: Q1.1, U1.17
$$$30978: LF4.1, U1.1
$$$30982: LF3.1, U1.20
$$$30984: LF2.1, U1.19
GND: C1.1, C2.1, C3.1, C4.1, C9.1, CM1.1, CM2.1, CM3.1, CR1.1, Q1.2, Q1.4, RH.1, TRX-ANT.2, TRX-ANT.3, TRX-ANT.4, TRX-ANT.5, U1.5, U1.EP, U1.EP2, U1.EP3, U1.EP4, U1.EP5, U1.EP6, U1.EP7, U1.EP8, U1.EP9, U4.GND0, U4.GND1, U4.GND2, U4.GND3, U4.GND4, U4.GND5, U4.GND6, U4.GND7, U4.GND8, U4.GND9, U4.GND10, U4.GND11, U4.GND12, U4.GND13, U4.GND14, U4.GND15, U4.GND16, U4.GND17, U4.GND18, U4.GND19
RFVDD: C1.2, C2.2, C3.2, C4.2, SJ1.2, U1.6, U1.8
RFVDD_TX: C9.2, LC.2, SJ1.1
RXN: CR2.2, LR1.1, U1.3
RXP: CR1.2, LR1.2, LR2.2, U1.2
TRX2: C8.1, CM3.2, LM3.1, LM4.2
TX1: C0.2, LC.1, U1.4
TX3: C0.1, C6.2, CH.2, CR2.1, LH.2, LM1.2, LR2.1
TX4: C7.1, C8.2, CM2.2, LM2.1, LM3.2
TX6: C6.1, C7.2, CM1.2, LM1.1, LM2.2
TX7: CC.1, LM4.1
